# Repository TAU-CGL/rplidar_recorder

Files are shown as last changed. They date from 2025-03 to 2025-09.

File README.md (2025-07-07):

# rplidar-recorder
ROS2 package for continous recording of 2D LiDAR data, as well as an open source CAD model, easily 3D printed.
We describe the step-by-step process of construction the LiDAR recording device, which can be simply plugged into any power source,
and it starts recording two-dimensional point dlouc data.
We also provide post-processing code that transforms the `*.mcap.zstd` files recorded by the `rosbag` into machine-learning-friendly data.

Contraption

## Hardware

The device can be constructed with any Ubuntu micro-computer, and any two-dimensional LiDAR scanner.
However, for this repository (and the corresponding CAD models) we used the following:

* Raspberry Pi 4 Model B (2GB RAM)
* A 128 GB microSD card (While class performance can be varied, we used a V30 card)
* Any compatible USB C power adapter or power bank
* SLAMTEC RPLIDAR-C1 Laser Range Scanner
* HDMI cable + microHDMI to HDMI Adaptor
* Any HDMI compatible screen
* USB Keyboard and mouse
* PLA (we used black)
* 4x M2x20mm screws
* 4x M2x10mm screws (M2x12mm is also fine)
* 4x M3x12mm screws (M3x16mm is also fine)
* 8x M2xNuts
* 8x M3xNuts
* 1x 3mm Red & 1X 3mm Green LEDs (see next section)
* 1x Red female jumper & 1x Black female jumper (see next section)
* 2x 220 Ohm resistors (see next ssection)

### Preparing LEDs

The contraption has two holes for LEDs: One red which states power on/off,
and one green which blinks when the ROS nodes properly run.
To connect the LEDs to the Raspberry Pi, we need to do some soldering:

1. Solder the 220 Ohm resistor to one of the LED cathodes (we used the positive).
    * An easy way to do so is to wrap one side of the resistor on the cathode
2. Strip two jumper cables (make sure that the unstripped end is a female connecter)
    * One red/white/purple/orange - positive
    * One brown/black/blue/green - negative
    * Each color pairing above was used repectively (e.g., blue + purple)
3. Solder the stripped end of each respective jumper cable to the LED cathodes
4. Optional: wrap the solder joints with tape (for aesthetics)

## Installation

### Physical construction

* Insert 4x M2x20mm screws through the base 
* Pad each screw with two M3 nuts, and tighten with one M2 nut
    * We recommed using pliers to tighten the M2 nuts.
* Place the raspberry pi, through the screws, and tighen with another M2 nut
* Connect the LiDAR to the top plate with 4x M2x10mm screws
    * Depening on the printer's settings, the holes can be rather narrow
    * You can use the screwdriver to make the gap less tight
    * You may also use the pliers to "guide" the screw
* Connect the top plate to the bottom plate with 4x M3x12mm screws
* Connect the soldered LEDs to the correct pins on the Raspberry Pi:

| Connector | Pin | Description |
| --- | --- | --- |
| Red (+) |  2  | 5V |
| Red (-) |  6  | GND |
| Green (+) | 32  | GPIO 12 |
| Green (-) | 34  | GND |

### Manual Setup

1. Download Ubuntu 22.04 server for Raspberry Pi, via the Raspberry Pi Imager [https://www.raspberrypi.com/software/](https://www.raspberrypi.com/software/), and flash it onto the microSD card.
2. Connect the RPi to the power, the screen and the keyboard.
3. Upon first login, the username and password are both `ubuntu`. You will be asked to change the password.
4. Optional: Increase font size. Run: `sudo nano /etc/default/console-setup` and change the value of `FONTSIZE` to `FONTSIZE=16x32`, then `sudo update-initramfs -u` and `sudo reboot`.
5. If you are not connected to the network by Ethernet, you need to setup a WiFi connection with netplan [https://dev.to/joeneville_/configure-ubuntu-wifi-with-netplan-4je0](https://dev.to/joeneville_/configure-ubuntu-wifi-with-netplan-4je0).
6. Run `sudo apt-get update` and `sudo apt-get upgrade`.
7. Optional: Install [ohmybash](https://github.com/ohmybash/oh-my-bash), change `di` color in `LS_COLORS` to `di:01;96:`:
    ```
    echo "export LS_COLORS=\"$LS_COLORS\"" >> ~/.bashrc
    ```
    Then edit the value of `di`. Change (in `.bashrc`) the ohmybash theme to `OSH_THEME="bakke"`

8. Install [ROS2 Humble](https://docs.ros.org/en/humble/Installation/Ubuntu-Install-Debs.html) with build tools, and add it the `.bashrc`: `echo "source /opt/ros/humble/setup.bash" >> ~/.bashrc`.
9. Optional: Install a minimal GUI for running `rviz2`.
    * Run: `sudo apt-get install xorg openbox`
    * Run: `sudo apt-get install tint2 xterm kitty`
    * Run: `echo "exec openbox-session" >> ~/.xinitrc`
    * Run: `mkdir ~/.config/openbox && echo "tint2" >> ~/.config/openbox/autostart`
10. Create the ROS2 workspace:
    * Run: `cd ~ && mkdir ros_ws && mkdir ros_ws/src && cd ros_ws/src`
    * Clone `rplidar_ros`: `git clone https://github.com/Slamtec/rplidar_ros.git`
    * Switch `rplidar_ros` to the `ros2` branch: `cd rplidar_ros && gco ros2 && cd ..`
    * Clone `rplidar_recorder`: `git clone https://github.com/TAU-CGL/rplidar_recorder.git`
    * Build the workspace: `cd ~/ros_ws && colcon build`
    * Source the workspace: `echo "source ~/ros_ws/install/setup.bash" >> ~/.bashrc`
11. Miscelenous steps:
    * Install `sudo apt-get install python3-gpiozero`
12. Run: `sudo chmod a+x /home/ubuntu/ros_ws/src/rplidar_recorder/scripts/launch.bash`
13. Run: `sudo crontab -e` and then add the line `@reboot /home/ubuntu/ros_ws/src/rplidar_recorder/scripts/launch.bash`
14. Set the correct timezone: `sudo timedatectl set-timezone <timeszone>` (Get timezone name with `timedatectl list-timezones`. Israel time is `Asia/Jerusalem`).

### Model Image

We finally note that one doesn't actually have to run this entire process for every recorder device;
You can use the imager to create an Ubuntu install already set with correct username/password, and connected to WiFi.
Then, you only need to run the `firstboot.sh` script:

    wget https://raw.githubusercontent.com/TAU-CGL/rplidar_recorder/refs/heads/main/firstboot.sh
    sudo chmod a+x firstboot.sh
    sudo ./firstboot.sh

Finally, update the remote server address:

    sudo nano /root/ros_ws/src/rplidar_recorder/scripts/launch.bash

And change the value of `SERVER_URL` to the correct one.

## Notes

* Although neither `ros2 topic echo /scan` nor `rviz2` then `/scan` topic work when the code runs from crontab, the `/scan` topic is accessible to other nodes running from crontab.

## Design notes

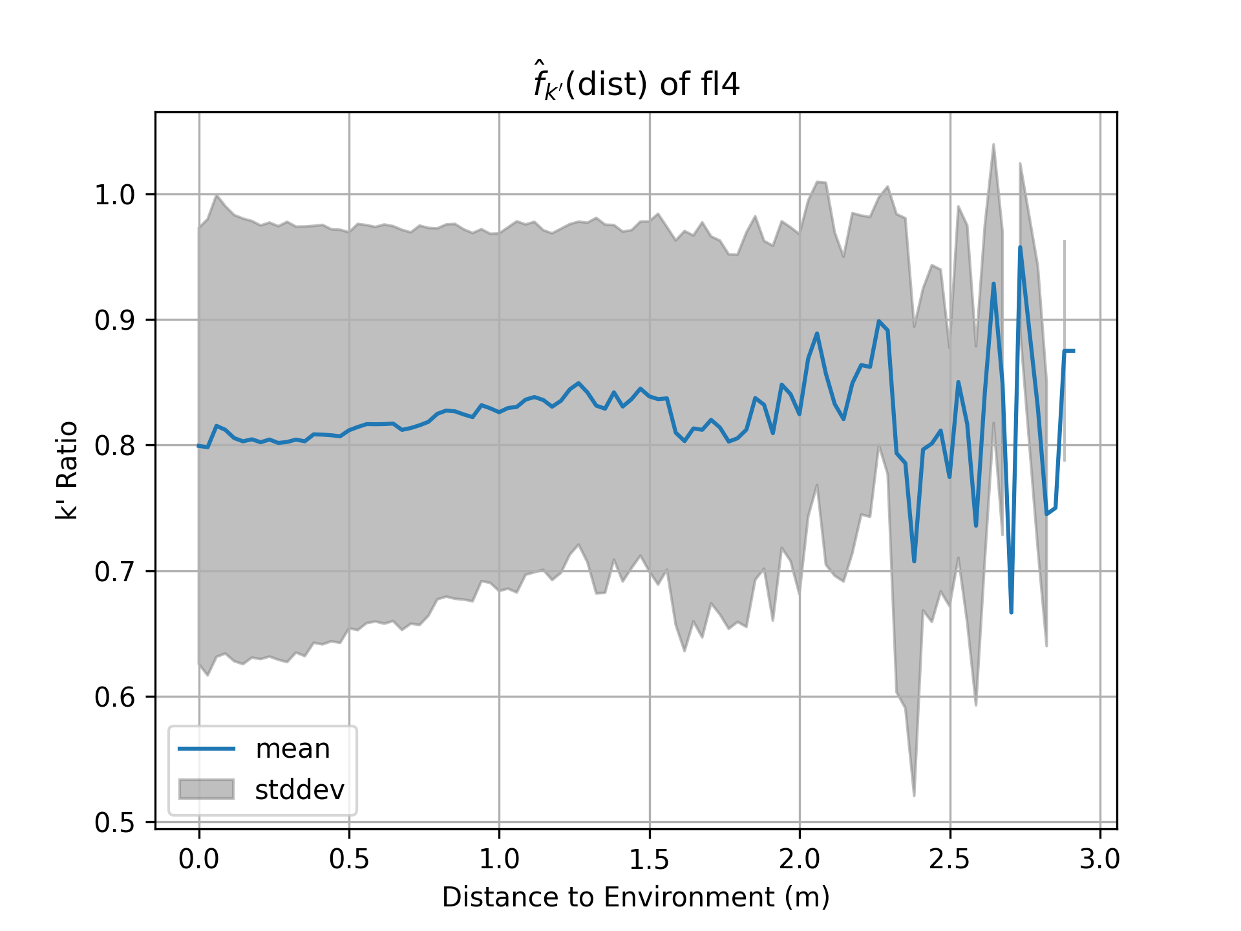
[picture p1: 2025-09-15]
parsing/hat_fkdist_fl4.png

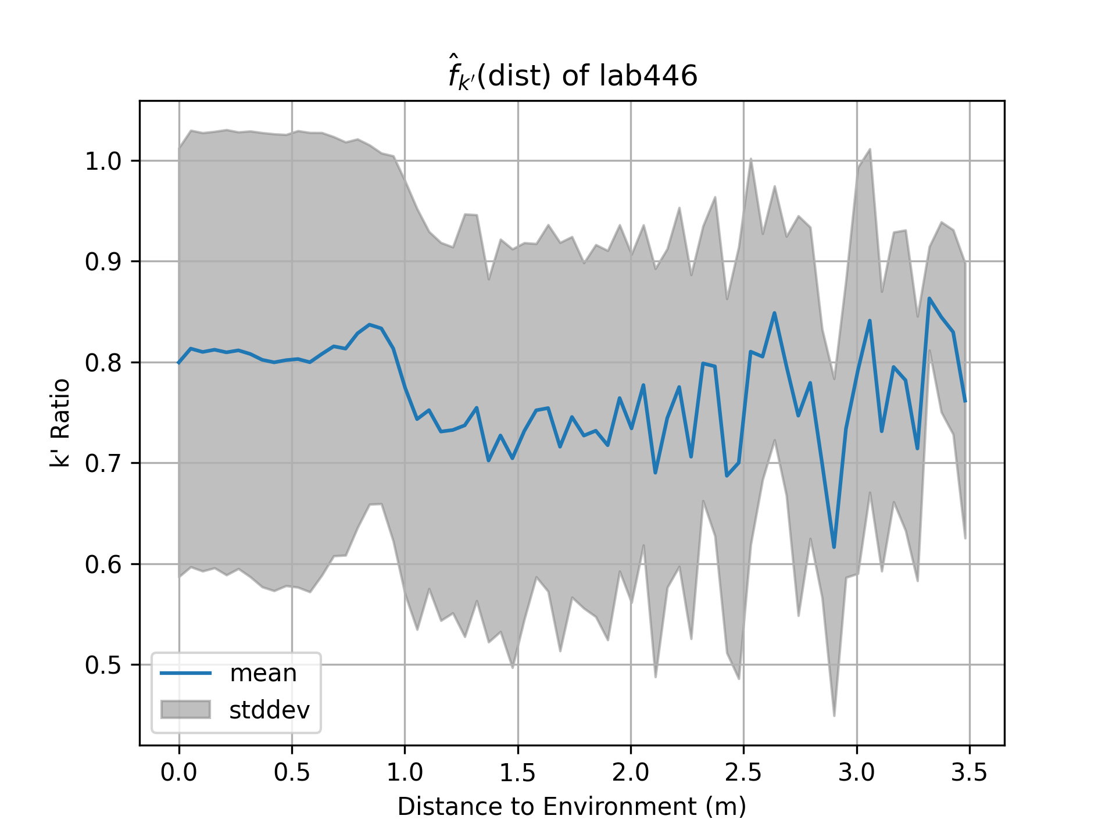
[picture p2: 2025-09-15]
parsing/hat_fkdist_lab446.png

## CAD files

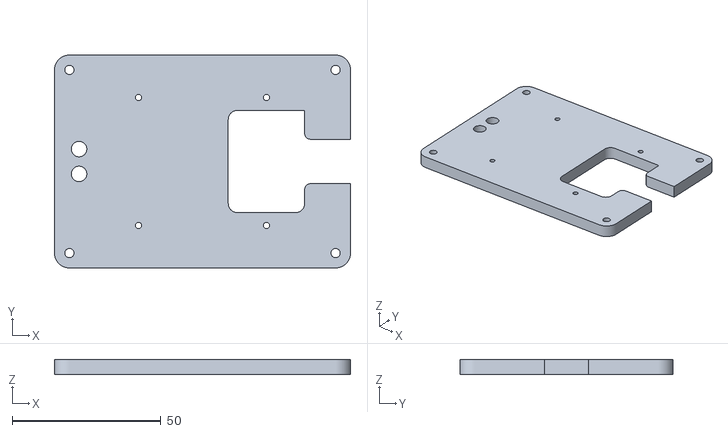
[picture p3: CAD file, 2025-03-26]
cad/lidar-recorder-TopPlate.stl
99.5 x 71.6 x 5.00

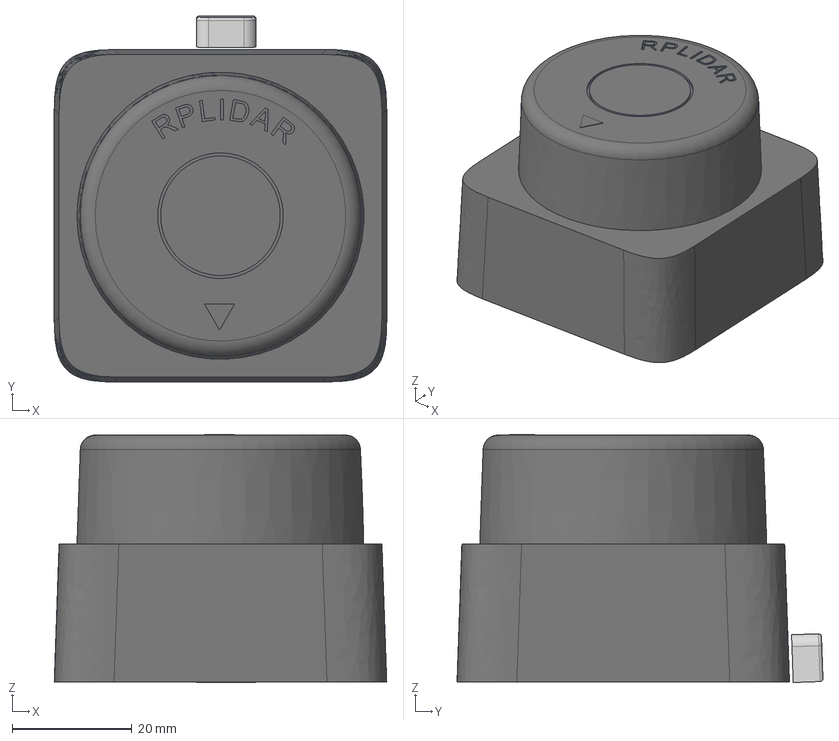
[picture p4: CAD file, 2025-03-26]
cad/raw/slamtec-rplidar-c1-1.snapshot.2/slamtec rplidar c1.step
55.6 x 61.2 x 41.5 mm

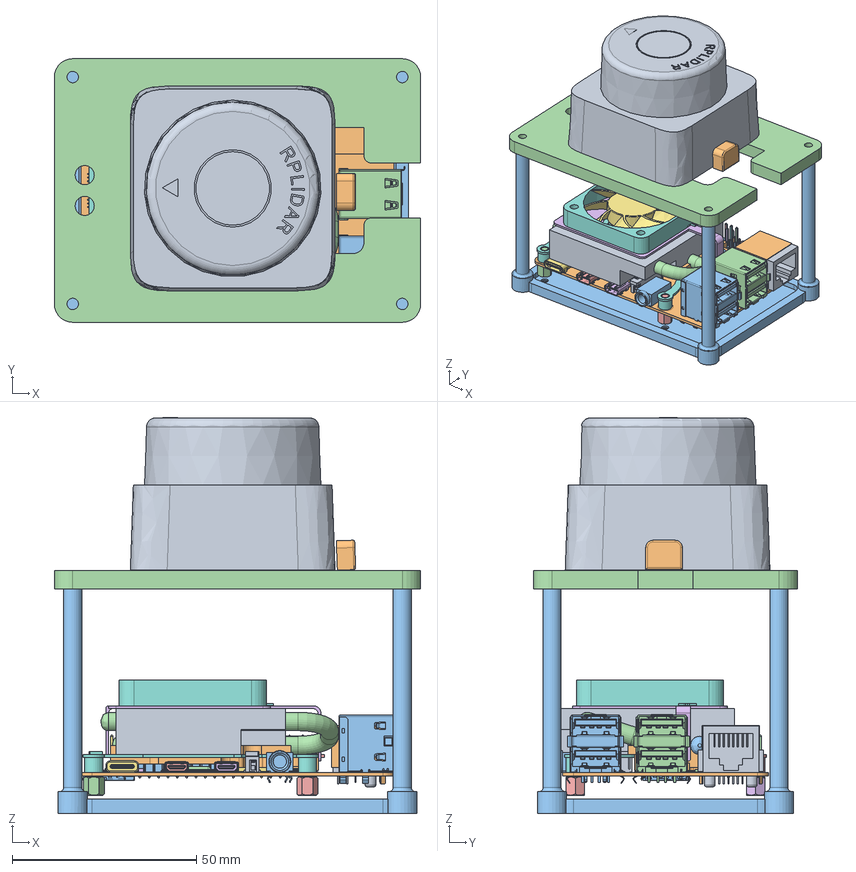
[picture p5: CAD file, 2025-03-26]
cad/raw/slamtec-rplidar-c1-1.snapshot.2/lidar-recorder.FCStd
99.5 x 71.6 x 107.6 mm
Raspberry-Pi-4-Model-B-03 v1
Raspberry-Pi-4-Model-B-03 v002
Raspberry-Pi-4-Model-B-03 v003
Raspberry-Pi-4-Model-B-03 v004
Raspberry-Pi-4-Model-B-03 v005
Raspberry-Pi-4-Model-B-03 v006
Raspberry-Pi-4-Model-B-03 v007
Raspberry-Pi-4-Model-B-03 v008
Raspberry-Pi-4-Model-B-03 v009
Raspberry-Pi-4-Model-B-03 v010
Raspberry-Pi-4-Model-B-03 v011
Raspberry-Pi-4-Model-B-03 v012
Raspberry-Pi-4-Model-B-03 v013
Raspberry-Pi-4-Model-B-03 v014
Raspberry-Pi-4-Model-B-03 v015
Raspberry-Pi-4-Model-B-03 v016
Raspberry-Pi-4-Model-B-03 v017
Raspberry-Pi-4-Model-B-03 v018
Raspberry-Pi-4-Model-B-03 v019
Raspberry-Pi-4-Model-B-03 v020
Raspberry-Pi-4-Model-B-03 v021
Raspberry-Pi-4-Model-B-03 v022
Raspberry-Pi-4-Model-B-03 v023
Raspberry-Pi-4-Model-B-03 v024
Raspberry-Pi-4-Model-B-03 v025
Raspberry-Pi-4-Model-B-03 v026
Raspberry-Pi-4-Model-B-03 v027
Raspberry-Pi-4-Model-B-03 v028
Raspberry-Pi-4-Model-B-03 v029
Raspberry-Pi-4-Model-B-03 v030
Raspberry-Pi-4-Model-B-03 v031
Raspberry-Pi-4-Model-B-03 v032
Raspberry-Pi-4-Model-B-03 v033
Raspberry-Pi-4-Model-B-03 v034
Raspberry-Pi-4-Model-B-03 v035
Raspberry-Pi-4-Model-B-03 v036
Raspberry-Pi-4-Model-B-03 v037
Raspberry-Pi-4-Model-B-03 v038
Raspberry-Pi-4-Model-B-03 v039
Raspberry-Pi-4-Model-B-03 v040
Raspberry-Pi-4-Model-B-03 v041
Raspberry-Pi-4-Model-B-03 v042
Raspberry-Pi-4-Model-B-03 v043
Raspberry-Pi-4-Model-B-03 v044
Raspberry-Pi-4-Model-B-03 v045
Raspberry-Pi-4-Model-B-03 v046
Raspberry-Pi-4-Model-B-03 v047
Raspberry-Pi-4-Model-B-03 v048
Raspberry-Pi-4-Model-B-03 v049
Raspberry-Pi-4-Model-B-03 v050
Raspberry-Pi-4-Model-B-03 v051
Raspberry-Pi-4-Model-B-03 v052
Raspberry-Pi-4-Model-B-03 v053
Raspberry-Pi-4-Model-B-03 v054
Raspberry-Pi-4-Model-B-03 v055
Raspberry-Pi-4-Model-B-03 v056
Raspberry-Pi-4-Model-B-03 v057
Raspberry-Pi-4-Model-B-03 v058
Raspberry-Pi-4-Model-B-03 v059
Raspberry-Pi-4-Model-B-03 v060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

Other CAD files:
cad/raw/lidar-recorder.FCStd
cad/raw/slamtec-rplidar-c1-1.snapshot.2/slamtec rplidar c1.f3d
cad/raw/slamtec-rplidar-c1-1.snapshot.2/slamtec rplidar c1.stl

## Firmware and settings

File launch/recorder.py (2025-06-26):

import datetime

from launch import LaunchDescription
from launch.actions import RegisterEventHandler, Shutdown, ExecuteProcess
from launch.events.process import ProcessStarted
from launch.event_handlers.on_process_start import OnProcessStart
from launch_ros.actions import Node

def generate_launch_description():
    rplidar_ros = Node(
            package='rplidar_ros',
            executable='rplidar_node',
            name='rplidar_node',
            exec_name='rplidar_node',
            parameters=[{'channel_type':"serial",
                        'serial_port': "/dev/ttyUSB0",
                        'serial_baudrate': 460800,
                        'frame_id': "laser",
                        'inverted': False,
                        'angle_compensate': True,
                        'scan_mode': "Standard"}],
            on_exit=Shutdown(),
            output='screen')
    
    green_led_blinker = Node(
        package='rplidar_recorder',
        executable='led_blinker',
        name='led_blinker',
        output='screen'
    )
    frame_link = Node( # For displaying the laser scan in rviz
        package="tf2_ros",
        executable="static_transform_publisher",
        arguments=["0", "0", "0", "0", "0", "0", "map", "laser"],
    )
    scan_uploader = Node(
        package='rplidar_recorder',
        executable='scan_uploader',
        name='scan_uploader',
        output='screen'
    )
    rosbag_uploader = Node(
        package='rplidar_recorder',
        executable='rosbag_uploader',
        name='rosbag_uploader',
        output='screen'
    )


    today = datetime.datetime.now()
    bag_name = today.strftime("%Y-%m-%d-%H-%M-%S")
    bag = ExecuteProcess(
        cmd=["ros2", "bag", "record", "/scan", "-d", "300", "-o", f"/home/ubuntu/rosbags/{bag_name}/", "--compression-mode", "file", "--compression-format", "zstd"],
        output="screen",
    )
    

    return LaunchDescription([
        RegisterEventHandler(event_handler=OnProcessStart(target_action=rplidar_ros, on_start=green_led_blinker)),
        RegisterEventHandler(event_handler=OnProcessStart(target_action=rplidar_ros, on_start=bag)),
        RegisterEventHandler(event_handler=OnProcessStart(target_action=rplidar_ros, on_start=scan_uploader)),
        RegisterEventHandler(event_handler=OnProcessStart(target_action=rplidar_ros, on_start=rosbag_uploader)),
        rplidar_ros,
        frame_link,
    ])

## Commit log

2025-03-25 Create initial launch files and led blinker
2025-03-25 Swap LED gpio pins
    [recorder.py]
2025-03-25 Modify red led code
2025-03-25 Move red led to seperate node
2025-03-25 Fix wrong rplidar params
    [recorder.py]
2025-03-26 Add CAD and image
    [lidar-recorder-TopPlate.stl, lidar-recorder.FCStd, slamtec rplidar c1.f3d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]
2025-06-25 First calibration algorithm
2025-06-26 Register laser scan model to admin page
2025-06-26 Updated calibration script
2025-07-07 Update also laserscan admin
2025-07-07 Filter laserscans correctly at contraption list endpoint
2025-07-08 Swap monitor device order
2025-07-21 Swap button order
2025-07-21 Calibration Script Updated #2
2025-07-23 Add the calibration fitting algorithm
2025-07-28 Sort devices list
2025-07-28 Start the calibration page
2025-07-28 Change calibration form layout
2025-07-28 Add calibration api
2025-08-28 Add a working calibration demo
2025-08-28 Add calibration endpoint
2025-08-28 Add the calibrate button in tab
2025-08-28 Change calibration result to 2D dict
2025-08-28 Add also visualize calibration
2025-08-28 Add visualize calibration endpoint to urls
2025-09-07 Add code to calibrate for floor4 kitchenette
2025-09-07 Add backup for kitchenette calibration values
2025-09-07 Allow not providing some devices
2025-09-15 Add the k prime evaluation
    [hat_fkdist_fl4_kitchenette.csv, hat_fkdist_lab446.csv]
